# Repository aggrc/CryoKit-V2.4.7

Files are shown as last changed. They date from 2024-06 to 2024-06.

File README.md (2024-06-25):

Efforts in development of germplasm repositories to preserve genetic resources of aquatic species are impeded globally by a lack of standardized, inexpensive, reproducible, and portable cryopreservation technologies.

The CryoKit is a 3-D printable device that supports reproducible cryopreservation with standard cooling rates (5 to 35°C/min). The CryoKit accommodates French straws (0.25 and 0.5-mL) and cryopreservation vials (0.5 and 2-mL).The CryoKit can be used with a standard Styrofoam container that holds liquid nitrogen for on-site sperm cryopreservation for aquatic species and is distributed as open hardware.

Developed by the Aquatic Germplasm and Genetic Resources Center (AGGRC) at the Louisiana State University Agricultural Center. The CryoKit was designed by Brittany Ratliff, E Hu, Bill Childress, Victoria Byrd, Yue Liu, Terrence Tiersch, and colleagues, in partnership with the Zebrafish International Resource Center (ZIRC) and USDA National Animal Germplasm Program (NAGP). This work was funded in part by NIH Office of Research Infrastructure Program (ORIP). This device is part of a multi-year project to develop a series of open hardware to support development of standardized and reproducible tools for the research communities that use aquatic models to study human diseases.

Please visit AGGRC.COM to learn more about our work.

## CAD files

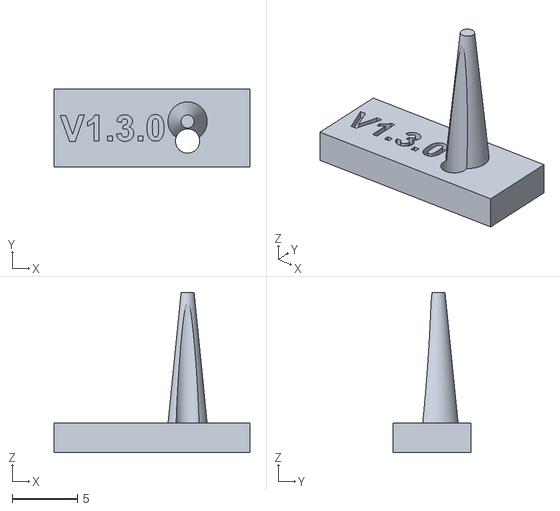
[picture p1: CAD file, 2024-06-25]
StrawThermocoupleFastener_V1.3.0.stl
15.0 x 6.00 x 12.2

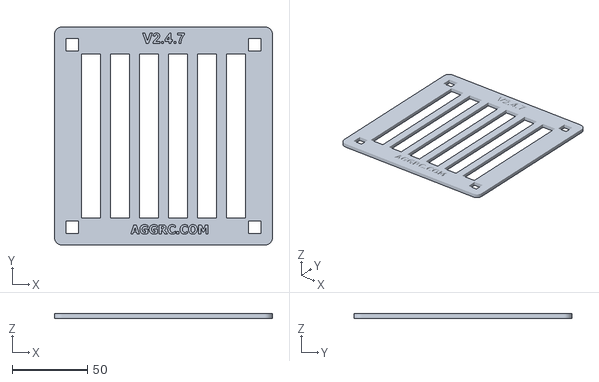
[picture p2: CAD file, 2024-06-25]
CryoKit_BottomRack_V2.4.7 v5.stl
145.0 x 145.0 x 3.17

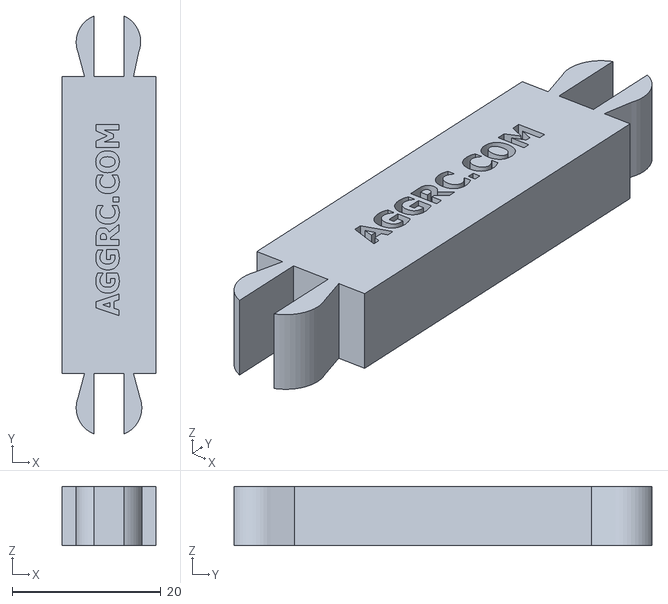
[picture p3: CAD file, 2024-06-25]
CryoKit_40mmClawLock_V2.4.7.stl
12.7 x 56.3 x 8.00

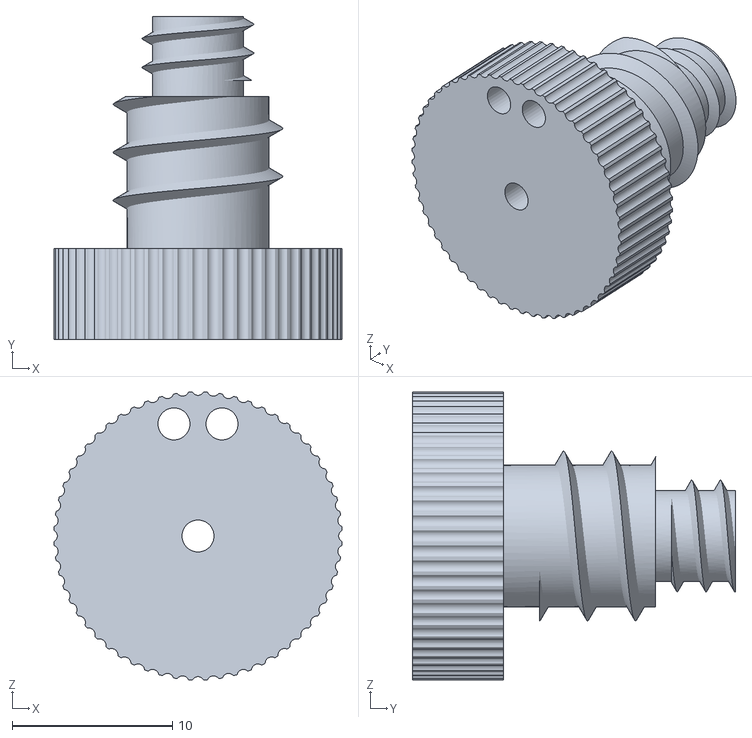
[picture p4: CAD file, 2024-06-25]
VialThermocoupleFastener_V1.2.0.stl
18.0 x 20.2 x 18.0

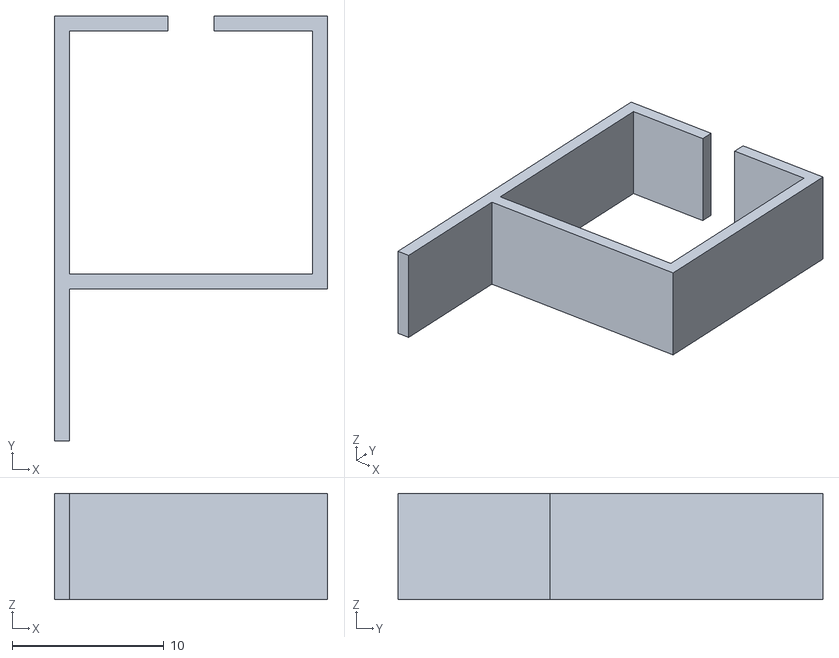
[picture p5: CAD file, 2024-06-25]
CryoKit_Clip_V2.4.7.stl
18.0 x 28.0 x 7.00

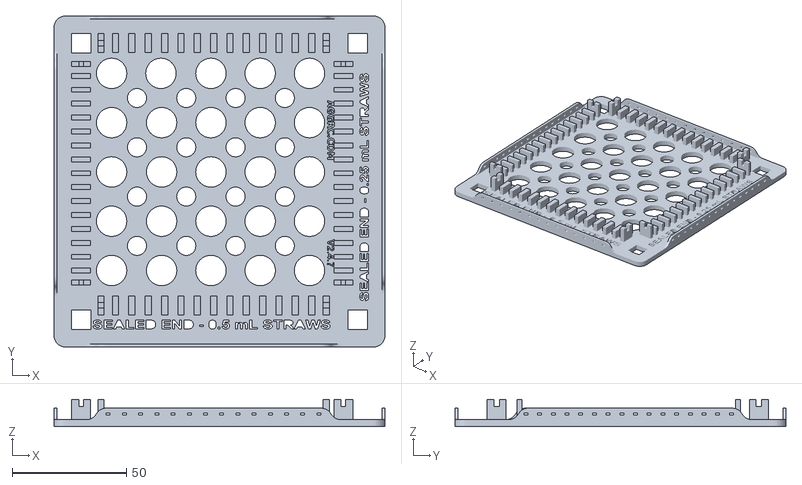
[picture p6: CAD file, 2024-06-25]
CryoKit_TopRack_V2.4.7 v1.stl
145.0 x 145.0 x 11.9

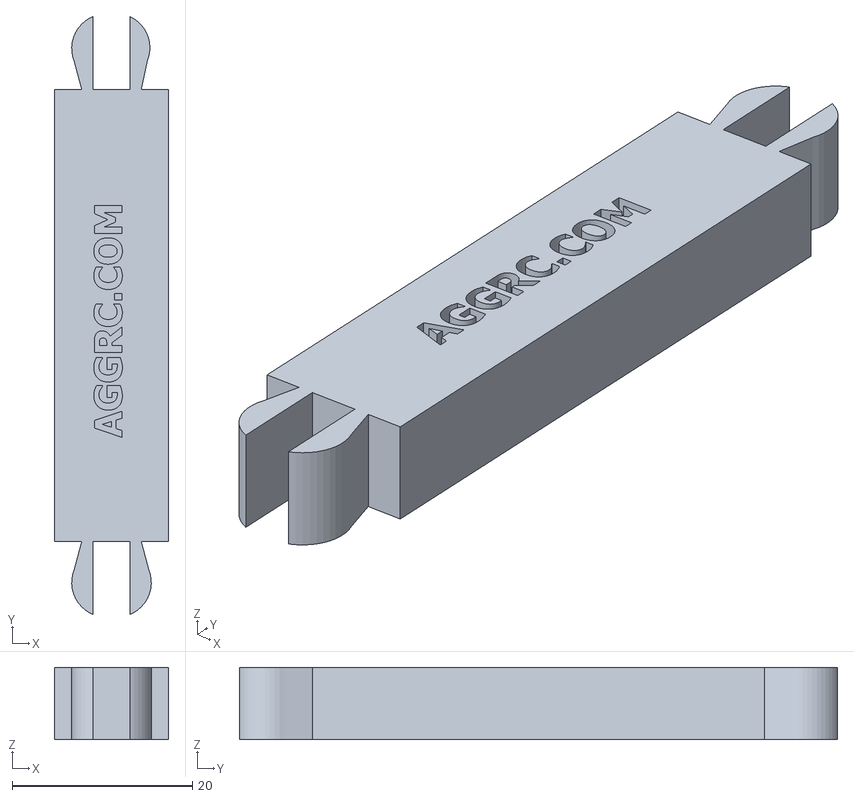
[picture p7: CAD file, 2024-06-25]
CryoKit_50mmClawLock_V2.4.7.stl
12.7 x 66.4 x 8.00

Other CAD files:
CryoKit_40mmClawLock_V2.4.7.f3d
CryoKit_50mmClawLock_V2.4.7.f3d
CryoKit_BottomRack_V2.4.7.f3d
CryoKit_Clip_V2.4.7.f3d
StrawThermocoupleFastener_V1.3.0.f3d
VialThermocoupleFastener_V1.2.0.f3d

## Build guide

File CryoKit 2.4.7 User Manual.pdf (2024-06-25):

# CRYOKIT V2.4.7 USER MANUAL

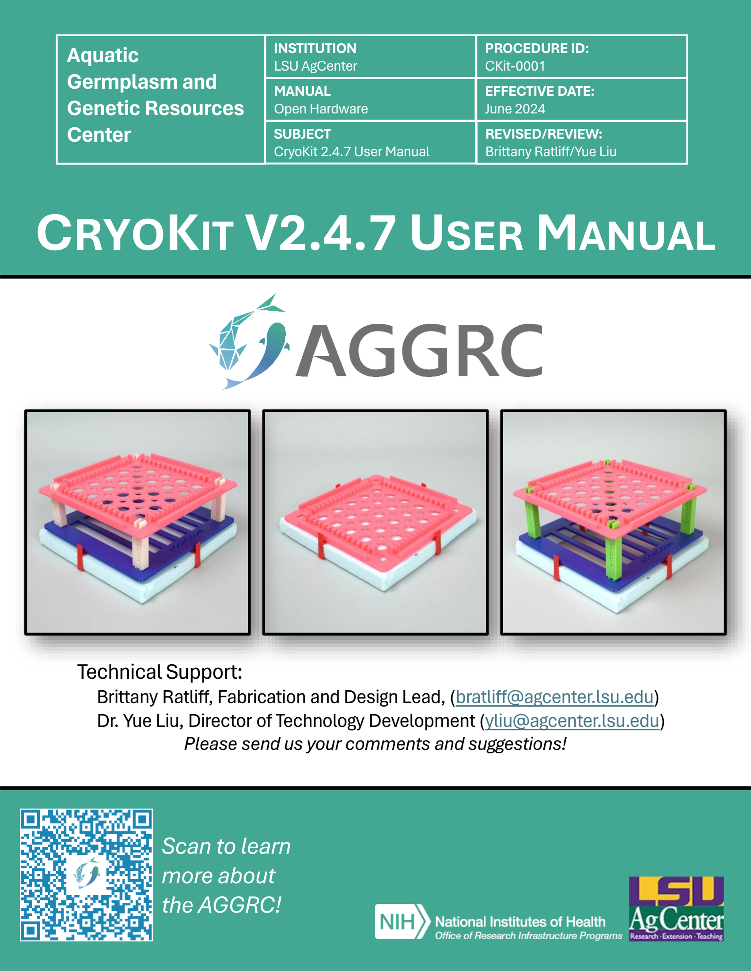
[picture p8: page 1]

Aquatic Germplasm and Genetic Resources Center | INSTITUTION LSU AgCenter | PROCEDURE ID: CKit-0001
| MANUAL Open Hardware | EFFECTIVE DATE: June 2024
| SUBJECT CryoKit 2.4.7 User Manual | REVISED/REVIEW: Brittany Ratliff/Yue Liu

Technical Support:
Brittany Ratliff, Fabrication and Design Lead, (bratliff@agcenter.lsu.edu) Dr. Yue Liu, Director of Technology Development (yliu@agcenter.lsu.edu) Please send us your comments and suggestions!

### Scan to learn more about the AGGRC!

# Table of Contents

## Page 1

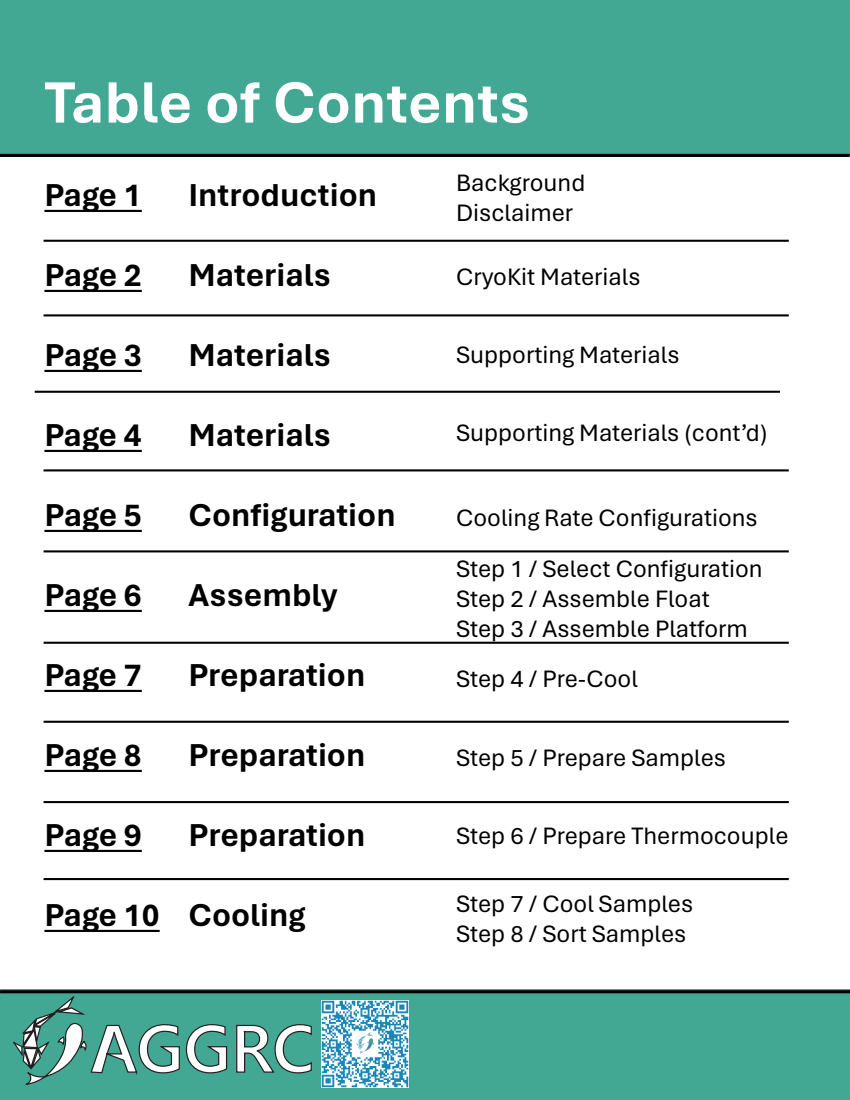
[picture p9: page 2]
Page 2; Page 3; Page 4; Page 5; Page 6; Page 7; Page 8; Page 9; Page 10; Introduction; Materials; Configuration; Assembly; Preparation; Cooling; Background Disclaimer; CryoKit Materials; Supporting Materials

Supporting Materials (cont’d)

Cooling Rate Configurations
Step 1 / Select Configuration
Step 2 / Assemble Float
Step 3 / Assemble Platform
Step 4 / Pre-Cool

Step 5 / Prepare Samples

Step 6 / Prepare Thermocouple

Step 7 / Cool Samples
Step 8 / Sort Samples

# Background

The Positional Cooling Platform Device (PCPD, known as the ‘CryoKit’) is a 3-D printable device that supports reproducible cryopreservation with standardizable cooling rates (5 to 35°C/min). The CryoKit accommodates French straws (0.25 and 0.5 mL), and cryopreservation vials (0.5 and 2 mL). Development of germplasm repositories to preserve genetic resources of aquatic species is impeded globally by a lack of standardized, inexpensive, reproducible, and portable cryopreservation technologies. The CryoKit can be used with a standard polystyrene container that holds liquid nitrogen for on-site cryopreservation for aquatic species and is distributed as open hardware. Creative Commons license: CC-BY-NC-SA.

The CryoKit was developed by the Aquatic Germplasm and Genetic Resources Center (AGGRC) at the Louisiana State University Agricultural Center by E Hu, Bill Childress, Brittany Ratliff, Victoria Byrd, Yue Liu, Terrence Tiersch, and colleagues, in partnership with the Zebrafish International Resource Center (ZIRC) and USDA National Animal Germplasm Program (NAGP). This work was funded primarily by NIH Office of Research Infrastructure Program (ORIP). This device is part of a multi-year project for development of a series of open-hardware devices to support standardized and reproducible tools for research communities that use aquatic models to study human disease.

Details about the development of the CryoKit can be found in the publication: Hu, E., Childress, W., & Tiersch, T. R. (2017). 3-D printing provides a novel approach for standardization and reproducibility of freezing devices. Cryobiology, 76, 34–40. The 3-D files for the CryoKit can be found on the AGGRC website and NIH 3D Print Exchange: https://3d.nih.gov/users/aggrc.lsuac

Please visit AGGRC.com to learn more about our work.

Disclaimer: Some materials (e.g., polystyrene) can heavily influence cooling rates. Other materials may be used; however, the cooling rate must be calibrated. Tracking the cooling rate every run is strongly recommended. Not all assembly configurations are described. Users are responsible for the safe handling of liquid nitrogen and samples. The cooling rate may vary slightly between runs. Tampering with thermocouples may lead to erroneous temperature data.
1

# CryoKit Materials

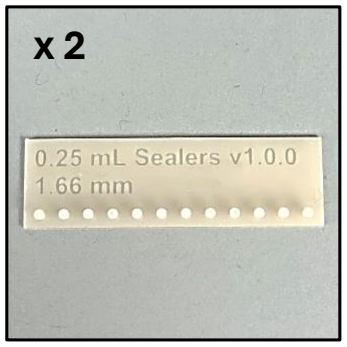
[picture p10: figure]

2

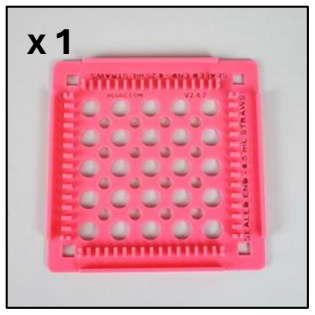
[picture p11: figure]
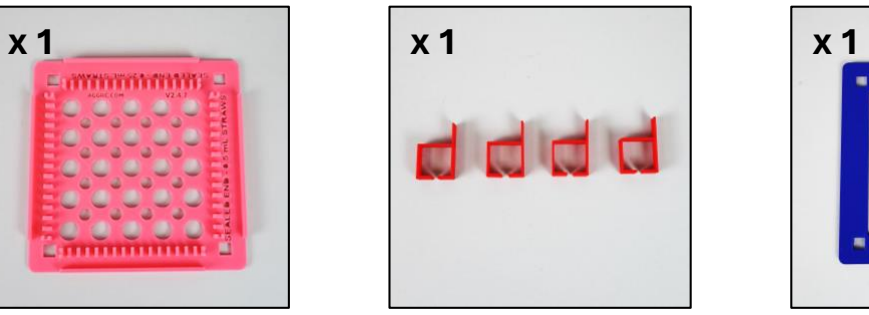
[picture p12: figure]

Top Rack*
Required

Clips*
Required

Bottom Rack*
Optional

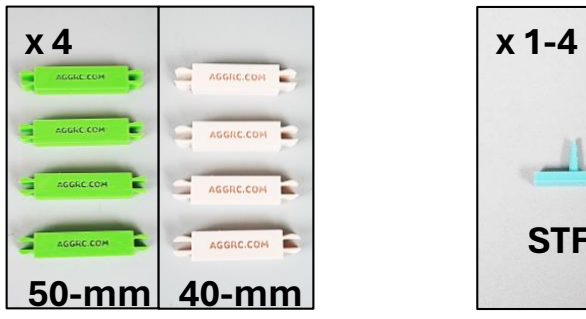
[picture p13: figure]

Claw Locks*
50-mm or 40-mm
Optional

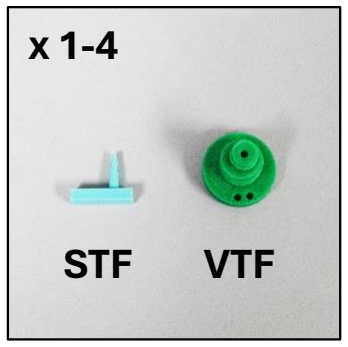
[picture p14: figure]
STF; VTF

Straw
Thermocouple
Fastener (STF)*
or
Vial Thermocouple
Fastener (VTF)*
Required

*3-D files can be found at: https://3d.nih.gov/users/aggrc.lsuac

Complete or Outer
Polystyrene Float
Required

Lowe’s (in US)
Polystyrene 0.55’’
Insulation Board
(Item # 15348)
Complete Float:
152 x 152 mm
Middle Section:
127 x 127 mm

Note: Color will vary for 3-D printed parts.

Straw Sealers*
0.25 mL or 0.5 mL
Optional

# Supporting Materials

3

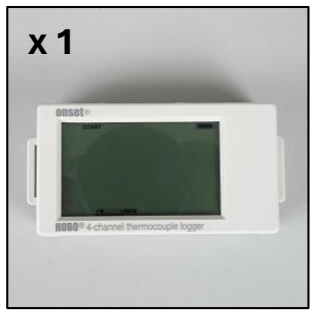
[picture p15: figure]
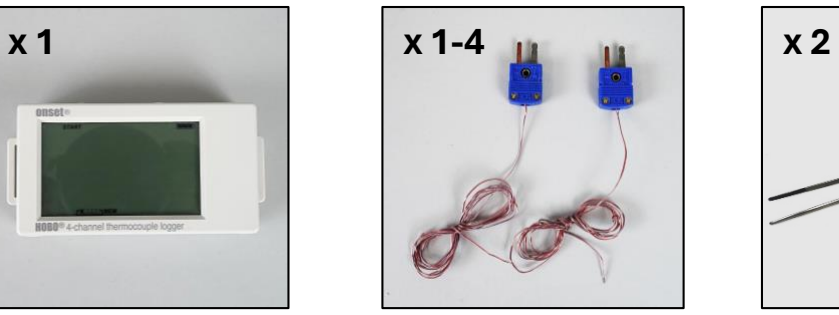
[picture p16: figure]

Data Logger or
Thermometer
Required

TL0021 Type-T
Thermocouple
Required

Cryogenic
Gloves
Required

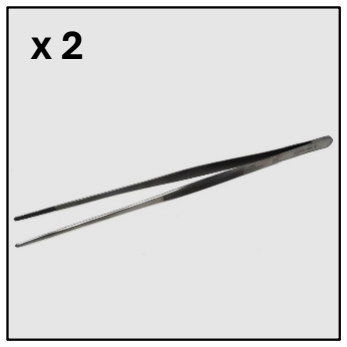
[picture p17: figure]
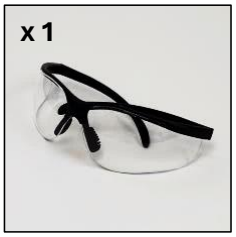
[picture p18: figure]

Safety
Glasses
Required

12” Forceps
Required

Polystyrene
Containers
Required
Polar Tech
Industries
1) Insulated Bio
Foam Container
(Item # 214 F)
2) Nestable
Insulated Shipper
(Item # NS-9KD)

Liquid Nitrogen
Required

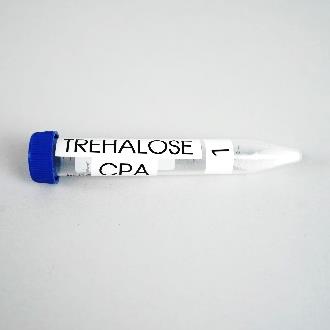
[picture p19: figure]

Cryoprotectant
Buffer Solution
Required

# Supporting Materials (cont’d)

4

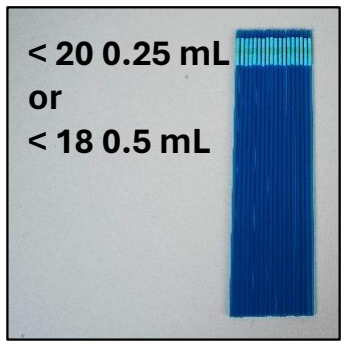
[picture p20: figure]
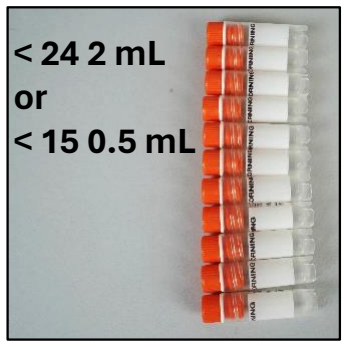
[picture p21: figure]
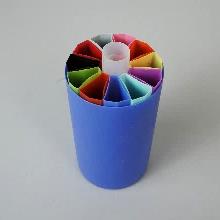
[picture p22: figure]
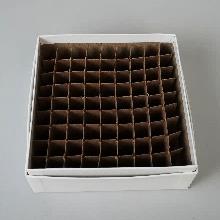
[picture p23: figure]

Required, depending on storage container preference

For Straws | For Vials
Daisy Goblet | Cane | Freezer Box

+ Visotube

1 mL Syringe
Required

200 µL
Pipette Tip
Optional

Cryopreservation
French Straws | Corning® 2 mL
| Cryovials (Item # 431386) Bank-It 0.5 mL Cryovials (Item # 374075) Cryovials

OR

# Cooling Rate Configurations

5

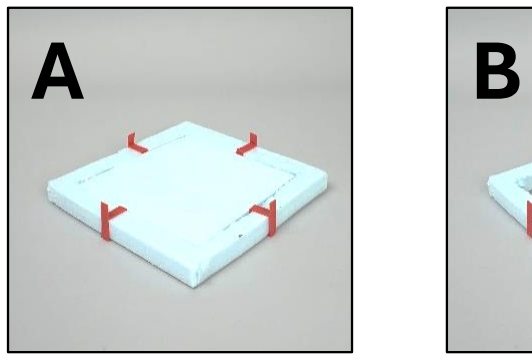
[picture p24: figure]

Cooling Rate (°C/min)

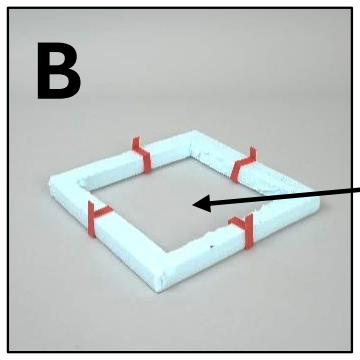
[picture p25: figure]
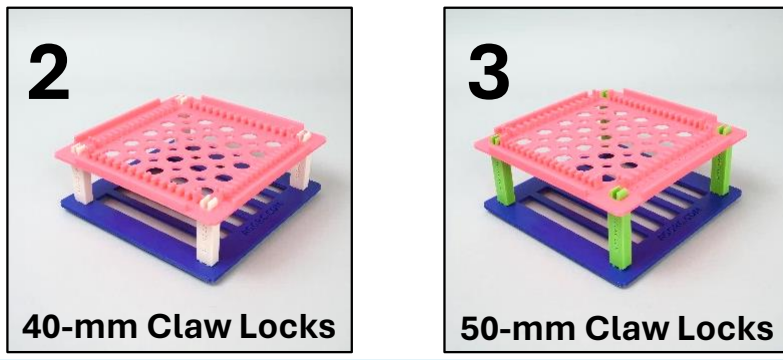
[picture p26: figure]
40-mm Claw Locks; 50-mm Claw Locks

Bank-It 0.5-mL
Cryovial Volume &
Configurations

Corning® 2-mL
Cryovial Volume &
Configurations
5-7 | 500 µL, 2+A | 500-1000 µL, 2+A
9-11 | 100 µL, 2+A | 500 µL, 2+A
14-17 | 51-100 µL, 3+A | 100 µL, 3+A
24-25 | 50 µL, 2+A | N/A

Open
Center

This User Manual details the assembly and cooling of configuration 1+A. However, other configurations still follow this manual.

Cooling Rate (°C/min) | 0.5-mL Straw Configurations | 0.25-mL Straw Configurations
≈ 5 | 3+B | 3+B
10-15 | 1+A | 2+B
20-25 | 1+B | 1+A

# Assembly

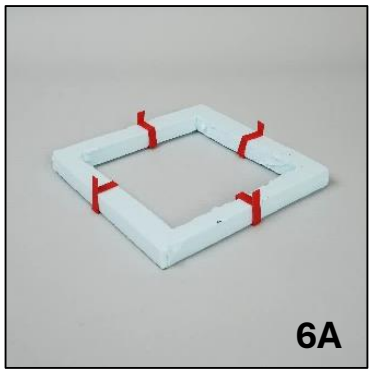
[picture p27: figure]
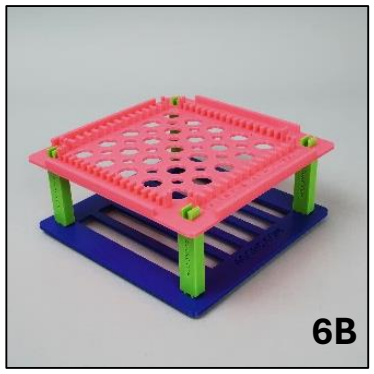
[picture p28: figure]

6

## 2) Assemble Polystyrene Float

2.1) Using a sharp blade or foam cutter, cut a square from the polystyrene sheet with dimensions of 152 mm².
2.2) | Using | the | same | piece, | cut | the | middle | section | with
dimensions of 127 mm².
2.3) Gently open each Clip and place them around each side of the outer Polystyrene Float (Figure 6A).
2.4) Place the inner Polystyrene Float in the center if using configuration A.

## 3) Assemble Cooling Platform

Note: Skip this step is using configuration 1.

3.1) Depending on your selected configuration, insert either side of the 40-mm or 50-mm Claw Lock into the holes on the Bottom Rack.
3.2) Place the Top Rack on top of the Claw Locks. Align the holes and press each corner to snap them into place (Figure 6B).

## 1) Select Assembly Configuration

1.1) Select an assembly configuration. Refer to the chart on page 5. Note: Not all configurations are shown. Please assess the cooling rate for your configuration and cooler arrangement.

Materials:

# Preparation

7

## 4) Pre-Cool

4.1) Put on Cryogenic Gloves and Safety Glasses.
4.2) With the smaller Polystyrene Container inside the larger, add liquid nitrogen to the smaller Polystyrene Container to a depth of 10-cm (9.5 cm – 10.5 cm, about 5 L). Marking the 10-cm line in the smaller container may help with filling (Figures 7A, 7B).
Note: The liquid nitrogen level decreases by 0.5 - 1 cm per cooling run, which does not affect performance. However, the liquid nitrogen level should be adjusted if it has dropped below 9.5-cm. Check the level after every cooling run.
4.3) Pre-cool the Polystyrene Float. Lower the float onto the liquid nitrogen and close both Polystyrene Containers (Figures 7C, 7D).
Note: If the Polystyrene Float is not pre-cooled, the liquid nitrogen will boil when samples are lowered which will cause variable cooling rates.
4.4) Set an equilibration timer for a minimum of 5-min after closing both Polystyrene Containers, ensuring a temperature gradient is established. The temperature gradient must be established before cooling samples. Note: After equilibration, both Polystyrene Containers must remain closed.

7A

7B

7D

7C

# Preparation

8

## 5) Prepare Samples

5.1) Set a timer and equilibrate your sample and Cryoprotectant.
5.2) Considering the number of Thermocouples planned to be used, fill up to 17 0.25-mL straws , 15 0.5-mL straws, 24 2-mL Corning® vials, or 15 0.5-mL Bank-it vials.
5.3A) To fill French Straws, place the small end of the 200-µL Pipette Tip into the 1-mL Syringe. Insert the cotton end of the French Straw into the 200-µL Pipette Tip (Figure 8A). Insert the end of the straw into solution and pull back on the plunger to fill the straw with the appropriate volume (Figure 8B). Remove the straw from the solution and pull the syringe plunger all the way back.
5.3B) To fill Cryovials, use the Syringe or a pipette to measure the appropriate volume of solution and fill the Cryovial.
5.4A) If there is no available process in your laboratory to seal French Straws, insert one of the tips of the Straw Sealers into a French Straw (Figure 8C), then bend the straw to break off the Straw Sealer and create a seal (Figure 8D).
5.4B) Close the filled Cryovials with their original cap.
5.5) Fill 1-4 French Straws or Cryovials with the approximate volume of Cryoprotectant solution for your Thermocouples. Keep these containers unsealed or uncapped and separate them from the sample-holding straws for step 6.

8A

8B

8C

8D

# Preparation

9

## 6) Fasten Thermocouples

6.1A) Identify which side of the Top Rack holds 0.25 or 0.5-mL straws. Insert the end of the Thermocouple through any slot on the correct side of the Top Rack. Insert the end of the Thermocouple through the hole on the Straw Thermocouple Fastener (STF) (Figure 9A).
6.1B) Insert the end of the Thermocouple through any slot on any side of the Top Rack. Insert the end of the Thermocouple through the top and into a hole on the edge of the Vial Thermocouple Fastener (VTF), then insert the end back through the other hole on the edge of the VTF. Then insert the Thermocouple through the hole in the center of the VTF (Figure 9B).
6.3) Insert the Thermocouple into the French Straw or Cryovial filled with Cryoprotectant solution that was set aside in the previous section. Position the Thermocouple so the tip is centered in the straw or vial. 6.4A) Align the tip of the STF with the French Straw and gently press the STF into the straw to fasten the Thermocouple (Figure 9C).
6.4B) Screw the VTF onto the Cryovial. Gently pull the Thermocouple to fasten it to the VTF.
6.5) Repeat the above steps for any additional Thermocouples, then connect the Thermocouples to the Data Logger.
6.6A) Place all French Straws on the Top Rack and secure them by placing two additional unfilled French Straws into the straw locks (Figure 9D).
Note: It’s recommended to use different colored straws for the locks so it’s easier to identify them after cooling. 6.6B) Place Cryovials on the Top Rack.

9A

9B

9C

9D

Straw Locks

# Cooling

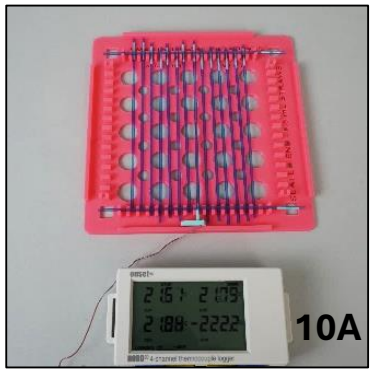
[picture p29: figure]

## 7) Cool Samples

7.1) Turn on the Data Logger/Thermometer (Figure 10A).
7.2) Open the Polystyrene Containers and gently place the CryoKit on the Polystyrene Float without leaving the containers open for longer than 10 seconds (Figure 10B). Note: Do not remove the Polystyrene Float from the containers. Ensure the CryoKit is centered and placed flat on the Polystyrene Float.
7.3) Close the Polystyrene Containers.
Note: Ensure both Polystyrene Containers are completely closed, and that the temperature gradient is not disturbed.
7.4) Continue to step 8 once the temperature has reached -80°C.

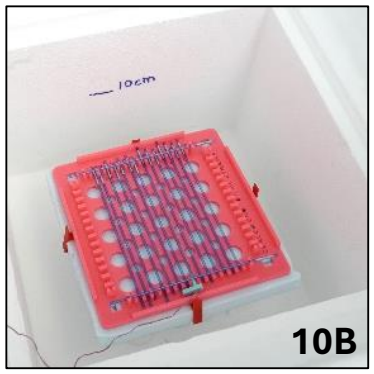
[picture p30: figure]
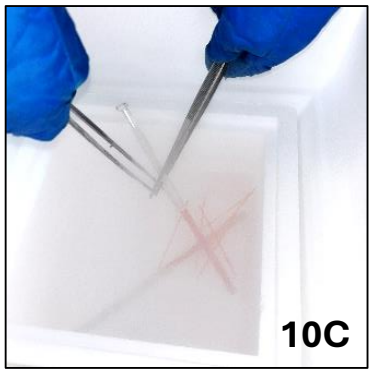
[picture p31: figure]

10

## 8) Sort Samples

8.1) Wearing Cryogenic Gloves and Safety Glasses, open the containers and use two 12” Tweezers to plunge the CryoKit into the Liquid Nitrogen.
8.2) Remove the straw locks (if applicable) and flip the Top Rack to dump the French Straws or Cryovials into the Liquid Nitrogen. Remove the Polystyrene Float and CryoKit and let the French Straws or Cryovials submerge into the Liquid Nitrogen.
8.3) Place the Daisy Goblet, Cane with or without the Visotube, or Freezer Box in the liquid nitrogen.
8.4A) Sort the French Straws into a Daisy Goblet or Canes with a Visotube for storage (Figure 10C).
8.4B) Sort the Cryovials into Canes or a Freezer Box.

Thank you for using the CryoKit V2.4.7. Your feedback is critical to AGGRC. Please fill out our feedback survey by scanning the QR code.
